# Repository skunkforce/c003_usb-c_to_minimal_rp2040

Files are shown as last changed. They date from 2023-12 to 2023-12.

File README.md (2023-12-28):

# edgy_board number c003
This design is part of the [edgy board project](https://github.com/skunkforce/edgy_boards).

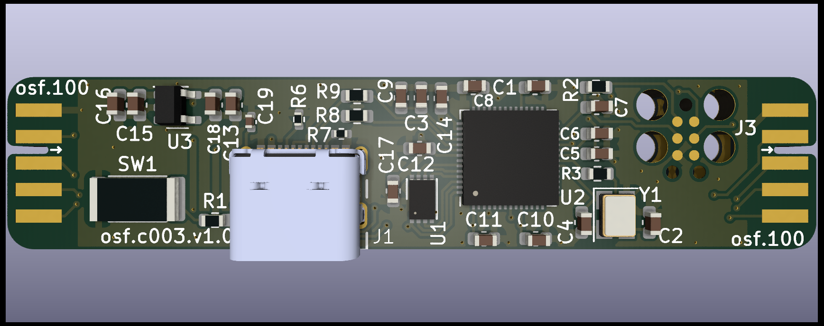
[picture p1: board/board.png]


# getting started
This repository uses submodules. After cloning use the command 

```$ git submodule update --init --recursive```

to pull the submodules before opening the project with kicad. 

# Tests
Tests can be found in [TESTS.md](TESTS.md)

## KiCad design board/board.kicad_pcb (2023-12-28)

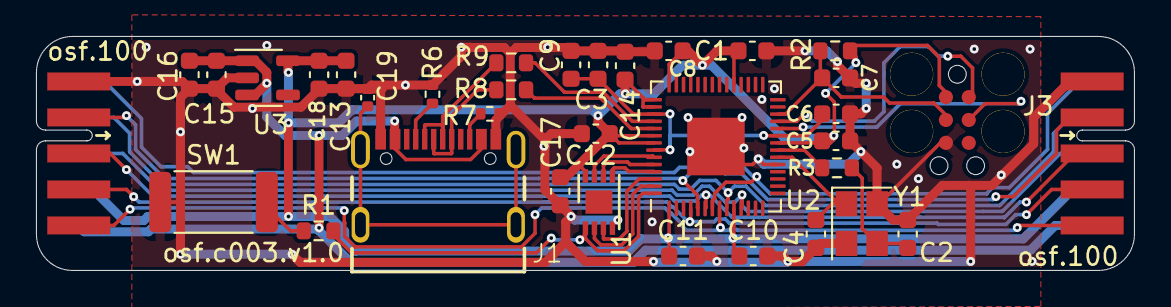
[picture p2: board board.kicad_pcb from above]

Board: 2 copper layers, 61.0 x 13.0 mm, 36 parts (1 on the bottom side), 31 nets.

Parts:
C1, C3, C5, C6, C8, C10, C11, C12, C15: 100nF; C_0603_1608Metric
C2, C4: 12pF; C_0603_1608Metric
C7: 1nF; C_0603_1608Metric
C9, C13, C14: 2.2uF; C_0603_1608Metric
C16, C18: 1uF; C_0603_1608Metric
C17: 10uF; C_0603_1608Metric
C19: 100pF; C_0402_1005Metric
J1: USB4105-GF-A; GCT_USB4105-GF-A
J2: 100_digital_IO; on_edge_2x05_device
J3: SWD_6_Pol_Needle; SWD6pol
J4: 100_digital_IO; on_edge_2x05_host
LOGO1: Logo_Open_Hardware_Small; OSHW-Symbol_6.7x6mm_SilkScreen
R1, R3: 1k; R_0603_1608Metric
R2: 10k; R_0603_1608Metric
R6, R7: 5.1k; R_0402_1005Metric
R8, R9: 27R; R_0603_1608Metric
SW1: PTS636 SK25J SMTR LFS; R_2512_6332Metric
U1: W25Q16JVUXIQ; DFN-8-1EP_3x2mm_P0.5mm_EP1.3x1.5mm
U2: RP2040; QFN-56-1EP_7x7mm_P0.4mm_EP3.2x3.2mm
U3: TLV743P; SOT-23-5
Y1: 12MhZ; Crystal_SMD_Abracon_ABM8G-4Pin_3.2x2.5mm

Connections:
+3V3: C1.1, C5.1, C8.1, C10.1, C11.1, C12.1, C13.1, C14.1, C17.1, C18.1, J2.9 (3.3V), J3.1 (VTref), J4.9 (3.3V), R2.1, U1.8 (VCC), U2.1 (IOVDD), U2.10 (IOVDD), U2.22 (IOVDD), U2.33 (IOVDD), U2.42 (IOVDD), U2.43 (ADC_AVDD), U2.44 (VREG_IN), U2.48 (USB_VDD), U2.49 (IOVDD), U3.5 (VOUT)
+5V: C15.1, C16.1, J1.A4/B9 (VBUS), J1.B4/A9 (VBUS), J2.10 (5V), J4.10 (5V), U3.1 (VIN), U3.3 (~SHDN)
/rp2040/DM: R9.2, U2.46 (USB_DM)
/rp2040/DP: R8.2, U2.47 (USB_DP)
/rp2040/GPIO6: J2.5 (IO3), J4.5 (IO3), U2.8 (GPIO6)
/rp2040/GPIO7: J2.7 (IO5), J4.7 (IO5), U2.9 (GPIO7)
/rp2040/QPI_SS: R1.2, U1.1 (~CS), U2.56 (QSPI_SS)
/rp2040/QSPI_CLK: U1.6 (CLK), U2.52 (QSPI_SCLK)
/rp2040/RUN: C7.1, J3.3 (nRes), R2.2, U2.26 (RUN)
/rp2040/SPI0_RX: J2.3 (IO1), J4.3 (IO1), U2.6 (GPIO4)
/rp2040/SPI0_SCK: J2.4 (IO2), J4.4 (IO2), U2.4 (GPIO2)
/rp2040/SPI0_TX: J2.2 (IO0), J4.2 (IO0), U2.5 (GPIO3)
/rp2040/SWCLK: J3.4 (SWCLK), U2.24 (SWCLK)
/rp2040/SWD: J3.2 (SWDIO), U2.25 (SWD)
/rp2040/UART1_TX: J2.8 (IO6), J4.8 (IO6), U2.11 (GPIO8)
/rp2040/~SPI0_CS: J2.6 (IO4), J4.6 (IO4), U2.7 (GPIO5)
/usb-c/DM: J1.A7 (DN1), J1.B7 (DN2), R9.1
/usb-c/DP: J1.A6 (DP1), J1.B6 (DP2), R8.1
GND: C1.2, C2.2, C3.2, C4.2, C5.2, C6.2, C7.2, C8.2, C9.2, C10.2, C11.2, C12.2, C13.2, C14.2, C15.2, C16.2, C17.2, C18.2, C19.2, J1.A1/B12 (GND), J1.B1/A12 (GND), J2.1 (GND), J3.5 (GND), J4.1 (GND), R6.2, R7.2, SW1.1, U1.4 (GND), U2.19 (TESTEN), U2.57 (GND), U3.2 (GND), Y1.2, Y1.4
unnamed: C2.1, R3.1, Y1.3
unnamed: C19.1, J1.G1 (SCHIELD), J1.G2 (SCHIELD), J1.G3 (SCHIELD), J1.G4 (SCHIELD)
unnamed: J1.A5 (CC1), R6.1
unnamed: J1.B5 (CC2), R7.1
unnamed: R1.1, SW1.2
unnamed: U1.5 (DI(IO0)), U2.53 (QSPI_SD0)
unnamed: U1.2 (DO(IO1)), U2.55 (QSPI_SD1)
unnamed: U1.3 (IO2), U2.54 (QSPI_SD2)
unnamed: U1.7 (IO3), U2.51 (QSPI_SD3)
unnamed: C3.1, C6.1, C9.1, U2.23 (DVDD), U2.45 (VREG_VOUT), U2.50 (DVDD)
unnamed: C4.1, U2.20 (XIN), Y1.1
unnamed: R3.2, U2.21 (XOUT)

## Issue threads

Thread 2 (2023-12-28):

the RP2040 does not allow arbitrary mapping of interfaces which makes the interface connector unusable for I2C and UART

odinthenerd, 2023-12-28:
The RP2040 does not allow arbitrary mapping of interfaces:
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

Therefore the pinning of the interface connector must be harmonized and if needed jumpers should be added to allow for the configuration of any osf.100 interface to be used on this connector. We should also take note that with this change the RP2040 logic analyzer software be usable without modification.

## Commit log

2023-11-28 added boot select button
    [board.kicad_pcb, board.kicad_sch, rp2040.kicad_sch]
2023-11-28 fixed boot select circuit
    [board.kicad_pcb, board.kicad_sch]
2023-12-28 added JLC parts
    [board.kicad_pcb]
